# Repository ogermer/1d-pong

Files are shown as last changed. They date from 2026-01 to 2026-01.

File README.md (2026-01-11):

# 1D Pong

A two-player reaction game played on a single strip of WS2812B LEDs. Players compete by pressing their button at the right moment when the ball enters their zone.

## Features

- Fast-paced two-player gameplay
- Dynamic difficulty: zones shrink after each point
- Early-hit bonus: hit the ball as it enters your zone for extra speed
- 13 attract mode animations to draw players in
- Modular animation system for easy customization
- Visual feedback for hits, misses, and scoring
- Configurable game parameters

## Hardware Requirements

### Components

| Component | Specification | Quantity |
|---|---|---|
| Microcontroller | WEMOS D1 Mini ESP32 | 1 |
| LED Strip | WS2812B, 55 LEDs | 1 |
| Buttons | Momentary push button | 2 |
| Power Supply | 5V, 3A recommended | 1 |
| Wires | Jumper wires | As needed |

### Schematic

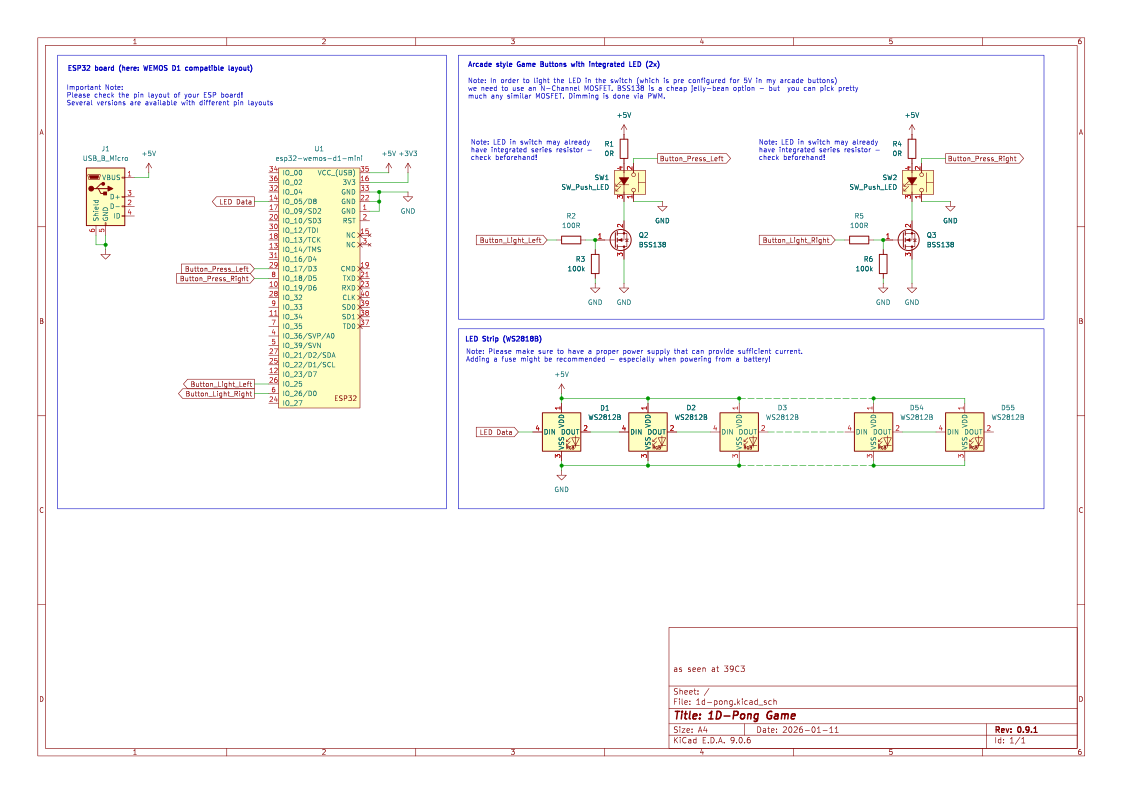
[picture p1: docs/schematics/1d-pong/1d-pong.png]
Schematic Diagram


[Download PDF Schematic](docs/schematics/1d-pong/1d-pong.pdf)

### Pin Connections

| Component | ESP32 Pin |
|---|---|
| LED Data | GPIO 5 |
| Left Button | GPIO 17 |
| Right Button | GPIO 18 |
| Left Button LED | GPIO 25 (PWM) |
| Right Button LED | GPIO 26 (PWM) |
| LED Power | 5V |
| LED Ground | GND |
| Buttons | GND (active LOW with internal pull-up) |

### Photos

<!-- Add your project photos to docs/images/ -->
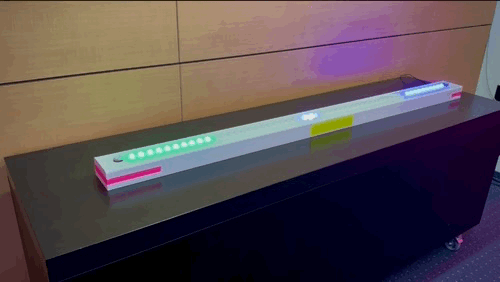
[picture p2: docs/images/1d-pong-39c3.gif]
Project Photo

<!-- ![Project Detail](docs/images/project-photo-2.jpg) -->

## Installation

### Prerequisites

- [VS Code](https://code.visualstudio.com/)
- [PlatformIO Extension](https://platformio.org/install/ide?install=vscode)

### Setup

1. Clone the repository:
   ```bash
   git clone https://github.com/yourusername/1d-pong.git
   cd 1d-pong
   ```

2. Open the project in VS Code:
   ```bash
   code .
   ```

3. Build the project:
   - Click the checkmark icon in the PlatformIO toolbar, or
   - Press `Ctrl+Alt+B`

4. Upload to your ESP32:
   - Connect your ESP32 via USB
   - Click the arrow icon in the PlatformIO toolbar, or
   - Press `Ctrl+Alt+U`

### Configuration

Edit `include/config.h` to customize:

```cpp
// Hardware
#define NUM_LEDS            55      // Number of LEDs in your strip
#define LED_PIN             5       // Data pin for LED strip
#define BUTTON_LEFT_PIN     17      // Left player button
#define BUTTON_RIGHT_PIN    18      // Right player button

// Button LEDs (PWM capable pins)
#define BUTTON_LED_LEFT_PIN  25     // Left button LED
#define BUTTON_LED_RIGHT_PIN 26     // Right button LED
#define BUTTON_LED_PWM_FREQ  5000   // 5kHz PWM frequency
#define BUTTON_LED_PWM_RES   8      // 8-bit resolution (0-255)

// Game Parameters
#define ZONE_SIZE_START     10      // Initial zone size (LEDs)
#define ZONE_SIZE_MIN       5       // Minimum zone size
#define SCORE_TO_WIN        5       // Points to win a match

// Speed
#define BALL_INITIAL_DELAY_MS  60   // Starting ball speed (lower = faster)

// Animation
#define ANIMATION_DURATION_MS  10000UL  // Duration per animation (ms)
```

## How to Play

### Starting a Game

1. When idle, the LED strip displays attract mode animations
2. Either player presses their button to start a match
3. The ball spawns in the center after a countdown

### Gameplay

1. The ball (white LED) travels toward one player's zone
2. When the ball enters your zone (colored section), press your button to return it
3. The ball speeds up with each successful return
4. Score a point when your opponent misses

### Scoring

- **Miss**: Ball exits the strip = opponent scores
- **Early press**: Pressing outside your zone = opponent scores
- **First to 5 points wins** the match

### Advanced Mechanics

- **Early-hit bonus**: Hitting the ball as it enters your zone (not waiting until it's about to exit) adds extra speed, making it harder for your opponent
- **Shrinking zones**: After each point, both zones shrink by 1 LED, increasing difficulty

## Game State Machine

```mermaid
stateDiagram-v2
    [*] --> IDLE
    IDLE --> SERVE : Button Press
    SERVE --> BALL_MOVING : Countdown Complete
    BALL_MOVING --> BALL_MOVING : Successful Hit
    BALL_MOVING --> CHECK_GAME_OVER : Miss or Penalty
    CHECK_GAME_OVER --> SERVE : Score < 5
    CHECK_GAME_OVER --> GAME_OVER : Score ≥ 5
    GAME_OVER --> IDLE : Win Animation Complete

    note right of IDLE
        Attract mode animations
        Button LED breathing & pulses
    end note

    note right of SERVE
        Countdown with visual pulse
        Zone shrinks after each point
    end note

    note right of BALL_MOVING
        Active gameplay
        Button LEDs indicate active zones
        Flash on hit, blink on miss
    end note

    note right of GAME_OVER
        Display winner animation
        First to 5 points wins
    end note
```

### States

| State | Description |
|---|---|
| `IDLE` | Attract mode - cycling through animations, waiting for player |
| `SERVE` | Countdown before ball launch, zones displayed |
| `BALL_MOVING` | Active gameplay - ball moving, checking for hits |
| `CHECK_GAME_OVER` | Evaluate if a player has won |
| `GAME_OVER` | Display winner animation, then return to idle |

## Adding Custom Animations

The animation system uses auto-registration - simply create a new `.cpp` file in `src/animations/` and it will be automatically included.

### Step-by-Step

1. Copy the template:
   ```bash
   cp src/animations/_template.cpp.example src/animations/my_animation.cpp
   ```

2. Edit your new file:
   ```cpp
   #include "animation.h"

   class MyAnimation : public Animation {
   public:
       MyAnimation(const char* name) : Animation(name) {}

       void reset() override {
           // Initialize state when animation starts
           _lastUpdate = 0;
       }

       void update(CRGB* leds, uint8_t numLeds) override {
           // Non-blocking timing
           if (millis() - _lastUpdate < 50) return;
           _lastUpdate = millis();

           // Your animation logic here
           fill_solid(leds, numLeds, CRGB::Black);
           // ...

           FastLED.show();
       }

   private:
       uint32_t _lastUpdate = 0;
   };

   // Register with a display name
   REGISTER_ANIMATION(MyAnimation, "My Animation");
   ```

3. Build and upload - your animation is now in the rotation!

### Animation Guidelines

- **Non-blocking**: Never use `delay()` - use `millis()` for timing
- **Call `FastLED.show()`**: Required to display your changes
- **Use `reset()`**: Initialize state variables when animation starts
- **Available helpers**: `fill_solid()`, `CHSV()`, `sin8()`, `qadd8()`, `qsub8()`, etc.

### Included Animations

| Animation | Description |
|---|---|
| Rainbow Dot | Rainbow background with bouncing white dot |
| Pong Demo | Simulated game demonstration |
| Plasma Comet | Plasma background with white comet trail |
| Cylon | Scanning red eye effect |
| Fire | Flames from both player zones |
| Sparkle | Twinkling stars with shooting stars |
| Duel Chase | Blue/green dots colliding |
| Heartbeat | Pulsing red heartbeat |
| Ocean Wave | Blue sine waves with foam |
| Bouncing Balls | Physics-based bouncing balls |
| Matrix Rain | Green digital rain |
| Lightning Storm | Random flashes with thunder |
| Color Breathing | Slow color pulsing |

## Troubleshooting

### LEDs not lighting up

- Check power supply voltage (5V) and amperage (3A recommended for 55 LEDs)
- Verify data pin connection (GPIO 5 by default)
- Ensure correct LED type in config (`WS2812B`)
- Check color order setting (`GRB` for most WS2812B strips)

### Buttons not responding

- Verify button connections to correct GPIO pins
- Buttons should connect between GPIO and GND (uses internal pull-up)
- Check for loose connections

### Upload fails

- Try holding BOOT button on ESP32 while uploading
- Check USB cable (some are power-only)
- Verify correct board selected in `platformio.ini`

### Game too fast/slow

- Adjust `BALL_INITIAL_DELAY_MS` in `config.h`
- Higher values = slower ball
- Recommended range: 40-80ms

## Project Structure

```
1d-pong/
├── platformio.ini          # PlatformIO configuration
├── include/
│   ├── config.h            # Game and hardware configuration
│   └── animation.h         # Animation base class
├── src/
│   ├── main.cpp            # Game logic and state machine
│   ├── animation.cpp       # Animation manager
│   └── animations/         # Animation implementations
│       ├── _template.cpp.example
│       ├── rainbow_dot.cpp
│       ├── fire.cpp
│       └── ...
└── README.md
```

## Development Note

This project was developed with assistance from AI tools (Claude, ChatGPT, etc.). All code has been reviewed and tested by the author.

## Contributing

Contributions are welcome! Here's how you can help:

1. **Fork** the repository
2. **Create** a feature branch (`git checkout -b feature/amazing-animation`)
3. **Commit** your changes (`git commit -m 'Add amazing animation'`)
4. **Push** to the branch (`git push origin feature/amazing-animation`)
5. **Open** a Pull Request

### Ideas for Contributions

- New attract mode animations
- Sound effects support (buzzer/speaker)
- Web-based configuration interface
- Score persistence (EEPROM)
- Tournament mode (best of N matches)
- Single-player mode with AI

## Future Improvements

- [ ] Add sound effects for hits and misses
- [ ] Web interface for configuration
- [ ] Bluetooth controller support
- [ ] High score tracking
- [ ] Adjustable difficulty modes
- [ ] More visual feedback options
- [x] Button LED integration for gameplay feedback and attract animations
  - Note: Button LEDs have integrated resistors for 5V operation and require level shifters or transistors/MOSFETs to drive from ESP32

## Credits

This project was inspired by a 1D Pong game seen at [38C3](https://events.ccc.de/) (38th Chaos Communication Congress).

Built with:
- [FastLED](https://github.com/FastLED/FastLED) - LED control library
- [PlatformIO](https://platformio.org/) - Development platform
- [Arduino-ESP32](https://github.com/espressif/arduino-esp32) - ESP32 Arduino core

## License

This project is licensed under the MIT License - see below for details.

```
MIT License

Copyright (c) 2025

Permission is hereby granted, free of charge, to any person obtaining a copy
of this software and associated documentation files (the "Software"), to deal
in the Software without restriction, including without limitation the rights
to use, copy, modify, merge, publish, distribute, sublicense, and/or sell
copies of the Software, and to permit persons to whom the Software is
furnished to do so, subject to the following conditions:

The above copyright notice and this permission notice shall be included in all
copies or substantial portions of the Software.

THE SOFTWARE IS PROVIDED "AS IS", WITHOUT WARRANTY OF ANY KIND, EXPRESS OR
IMPLIED, INCLUDING BUT NOT LIMITED TO THE WARRANTIES OF MERCHANTABILITY,
FITNESS FOR A PARTICULAR PURPOSE AND NONINFRINGEMENT. IN NO EVENT SHALL THE
AUTHORS OR COPYRIGHT HOLDERS BE LIABLE FOR ANY CLAIM, DAMAGES OR OTHER
LIABILITY, WHETHER IN AN ACTION OF CONTRACT, TORT OR OTHERWISE, ARISING FROM,
OUT OF OR IN CONNECTION WITH THE SOFTWARE OR THE USE OR OTHER DEALINGS IN THE
SOFTWARE.
```

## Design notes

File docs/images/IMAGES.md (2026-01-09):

# Image Assets

Place the following images in this directory:

## Required Images

| Filename | Description | Recommended Size |
|---|---|---|
| `wiring-diagram.png` | Wiring diagram showing ESP32, LED strip, and button connections | 800x600px |
| `project-photo-1.jpg` | Photo of the finished project (front view) | 1200x800px |
| `project-photo-2.jpg` | Photo of the finished project (detail/alternate view) | 1200x800px |

## Optional Images

| Filename | Description |
|---|---|
| `gameplay.gif` | Animated GIF showing gameplay |
| `attract-mode.gif` | Animated GIF showing attract animations |
| `components.jpg` | Photo of all components before assembly |

## Image Guidelines

- Use PNG for diagrams and screenshots
- Use JPG for photos
- Use GIF for animations (keep file size reasonable, <5MB)
- Optimize images for web viewing

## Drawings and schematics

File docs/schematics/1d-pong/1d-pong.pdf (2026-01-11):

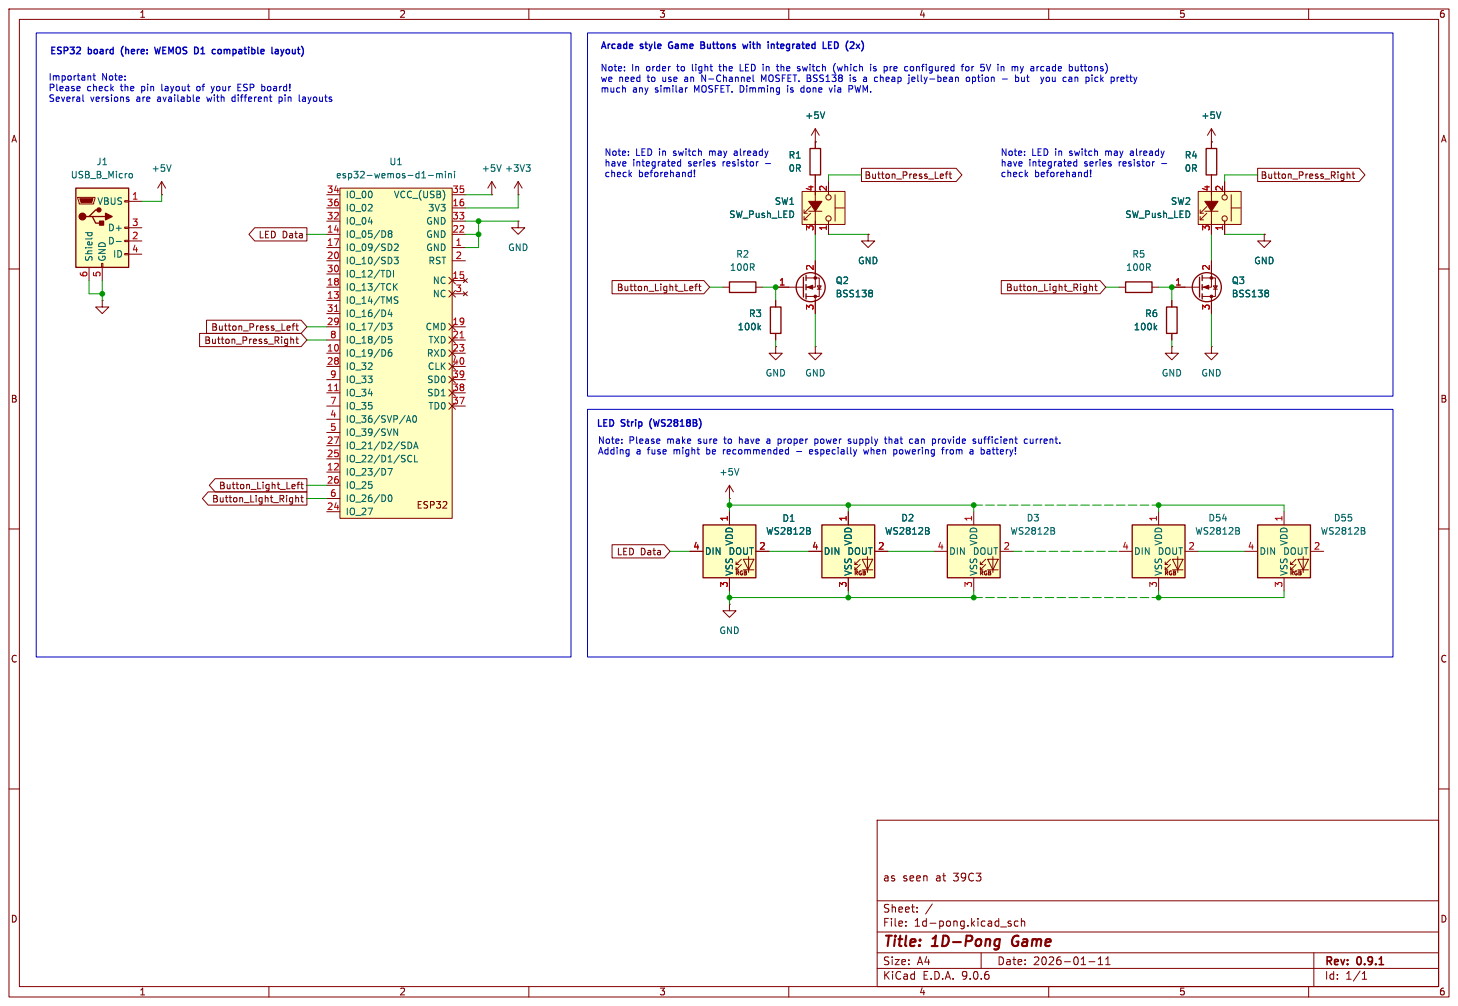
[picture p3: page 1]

File: 1d-pong.kicad_sch Sheet: / as seen at 39C3

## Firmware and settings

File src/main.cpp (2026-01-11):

#include <Arduino.h>
#include <FastLED.h>
#include "config.h"
#include "animation.h"
#include "button_led.h"

// ======================================================
// LED Array
// ======================================================
CRGB leds[NUM_LEDS];

// ======================================================
// Game State
// ======================================================
enum PlayerSide : uint8_t { PLAYER_LEFT = 0, PLAYER_RIGHT = 1 };

struct ButtonEvent {
    PlayerSide player;
    uint32_t   timestampMs;
};

QueueHandle_t buttonQueue;

enum GameState {
    STATE_IDLE,
    STATE_SERVE,
    STATE_BALL_MOVING,
    STATE_CHECK_GAME_OVER,
    STATE_GAME_OVER
};

volatile GameState currentState = STATE_IDLE;

int      ballPos        = NUM_LEDS / 2;
int      ballDir        = 1;
uint16_t ballDelayMs    = BALL_DELAY_START;
uint8_t  scoreLeft      = 0;
uint8_t  scoreRight     = 0;
uint8_t  currentZoneSize = ZONE_SIZE_START;
PlayerSide lastLoser    = PLAYER_LEFT;

// ======================================================
// Rendering Helpers
// ======================================================
void clearLeds() {
    fill_solid(leds, NUM_LEDS, COLOR_BACKGROUND);
}

void drawZones() {
    for (uint8_t i = 0; i < currentZoneSize; i++) {
        leds[i] = COLOR_ZONE_LEFT;
        leds[NUM_LEDS - 1 - i] = COLOR_ZONE_RIGHT;
    }
}

void drawBall() {
    if (ballPos >= 0 && ballPos < NUM_LEDS) {
        leds[ballPos] = COLOR_BALL;

        // 3-LED comet trail
        int t1 = ballPos - ballDir;
        int t2 = ballPos - 2 * ballDir;
        int t3 = ballPos - 3 * ballDir;

        if (t1 >= 0 && t1 < NUM_LEDS) {
            leds[t1] = CRGB::White;
            leds[t1].fadeToBlackBy(160);
        }
        if (t2 >= 0 && t2 < NUM_LEDS) {
            leds[t2] = CRGB::White;
            leds[t2].fadeToBlackBy(210);
        }
        if (t3 >= 0 && t3 < NUM_LEDS) {
            leds[t3] = CRGB::White;
            leds[t3].fadeToBlackBy(240);
        }
    }
}

void showKeypressFeedback(PlayerSide player) {
    CRGB savedLeft[ZONE_SIZE_START];
    CRGB savedRight[ZONE_SIZE_START];

    for (uint8_t i = 0; i < currentZoneSize; i++) {
        savedLeft[i]  = leds[i];
        savedRight[i] = leds[NUM_LEDS - 1 - i];
    }

    CRGB orange = CRGB(255, 80, 0);
    if (player == PLAYER_LEFT) {
        for (uint8_t i = 0; i < currentZoneSize; i++) leds[i] = orange;
    } else {
        for (uint8_t i = 0; i < currentZoneSize; i++) leds[NUM_LEDS - 1 - i] = orange;
    }

    FastLED.show();
    vTaskDelay(pdMS_TO_TICKS(80));

    if (player == PLAYER_LEFT) {
        for (uint8_t i = 0; i < currentZoneSize; i++) leds[i] = savedLeft[i];
    } else {
        for (uint8_t i = 0; i < currentZoneSize; i++) leds[NUM_LEDS - 1 - i] = savedRight[i];
    }

    FastLED.show();
}

void drawScoreOverlay() {
    const uint8_t c = NUM_LEDS / 2;
    for (uint8_t i = 0; i < scoreLeft && (c - 1 - i) >= 0; i++) {
        leds[c - 1 - i] += CRGB(0, 0, 100);
    }
    for (uint8_t i = 0; i < scoreRight && (c + 1 + i) < NUM_LEDS; i++) {
        leds[c + 1 + i] += CRGB(0, 100, 0);
    }
}

void showMissAnimation(PlayerSide p) {
    for (uint8_t f = 0; f < 3; f++) {
        clearLeds();
        if (p == PLAYER_LEFT) {
            for (uint8_t i = 0; i < currentZoneSize; i++) leds[i] = COLOR_MISS;
        } else {
            for (uint8_t i = 0; i < currentZoneSize; i++) leds[NUM_LEDS - 1 - i] = COLOR_MISS;
        }
        FastLED.show();
        vTaskDelay(pdMS_TO_TICKS(120));
        clearLeds();
        FastLED.show();
        vTaskDelay(pdMS_TO_TICKS(80));
    }
}

void showWinAnimation(PlayerSide w) {
    CRGB col = (w == PLAYER_LEFT) ? COLOR_WIN_LEFT : COLOR_WIN_RIGHT;
    for (uint8_t r = 0; r < 10; r++) {
        fill_solid(leds, NUM_LEDS, col);
        FastLED.show();
        vTaskDelay(pdMS_TO_TICKS(120));
        clearLeds();
        FastLED.show();
        vTaskDelay(pdMS_TO_TICKS(80));
    }
    currentZoneSize = ZONE_SIZE_START;
}

void resetMatch() {
    scoreLeft = scoreRight = 0;
    ballDelayMs = BALL_DELAY_START;
    lastLoser = PLAYER_LEFT;
    currentZoneSize = ZONE_SIZE_START;
}

int randomDirection() {
    return (random(0, 2) == 0) ? -1 : 1;
}

void prepareServe() {
    ballPos = NUM_LEDS / 2;
    ballDelayMs = BALL_DELAY_START;

    if (scoreLeft == 0 && scoreRight == 0) {
        ballDir = randomDirection();
    } else {
        ballDir = (lastLoser == PLAYER_LEFT) ? -1 : +1;
    }

    if (scoreLeft + scoreRight > 0 && currentZoneSize > ZONE_SIZE_MIN) {
        currentZoneSize--;
    }

    for (int c = 3; c > 0; --c) {
        clearLeds();
        drawZones();
        leds[NUM_LEDS / 2] = CRGB::Yellow;
        FastLED.show();
        ButtonLED::pulseCountdown(255);  // Bright pulse
        vTaskDelay(pdMS_TO_TICKS(200));
        clearLeds();
        drawZones();
        FastLED.show();
        ButtonLED::pulseCountdown(0);  // Off
        vTaskDelay(pdMS_TO_TICKS(200));
    }
    ButtonLED::setOff();  // Ensure off after countdown
}

// ======================================================
// Tasks
// ======================================================
void buttonTask(void* pvParameters) {
    (void)pvParameters;
    pinMode(BUTTON_LEFT_PIN, INPUT_PULLUP);
    pinMode(BUTTON_RIGHT_PIN, INPUT_PULLUP);

    bool lastL = digitalRead(BUTTON_LEFT_PIN) == BUTTON_ACTIVE_LEVEL;
    bool lastR = digitalRead(BUTTON_RIGHT_PIN) == BUTTON_ACTIVE_LEVEL;
    bool stableL = lastL, stableR = lastR;
    uint32_t changeL = millis(), changeR = millis();
    const uint32_t debounceMs = 20;

    for (;;) {
        uint32_t now = millis();
        bool rawL = digitalRead(BUTTON_LEFT_PIN) == BUTTON_ACTIVE_LEVEL;
        bool rawR = digitalRead(BUTTON_RIGHT_PIN) == BUTTON_ACTIVE_LEVEL;

        if (rawL != lastL) {
            lastL = rawL;
            changeL = now;
        } else if ((now - changeL) >= debounceMs && stableL != rawL) {
            stableL = rawL;
            if (stableL) {
                ButtonEvent ev{PLAYER_LEFT, now};
                xQueueSend(buttonQueue, &ev, 0);
            }
        }

        if (rawR != lastR) {
            lastR = rawR;
            changeR = now;
        } else if ((now - changeR) >= debounceMs && stableR != rawR) {
            stableR = rawR;
            if (stableR) {
                ButtonEvent ev{PLAYER_RIGHT, now};
                xQueueSend(buttonQueue, &ev, 0);
            }
        }

        vTaskDelay(pdMS_TO_TICKS(5));
    }
}

void gameTask(void* pvParameters) {
    (void)pvParameters;
    currentState = STATE_IDLE;

    AnimationManager& animManager = AnimationManager::getInstance();
    animManager.resetToFirst();

    Serial.printf("Loaded %d animations\n", animManager.getCount());

    for (;;) {
        switch (currentState) {

        case STATE_IDLE: {
            ButtonEvent ev;
            if (xQueueReceive(buttonQueue, &ev, 0) == pdTRUE) {
                resetMatch();
                clearLeds();
                FastLED.show();
                currentState = STATE_SERVE;
                break;
            }
            // Run attract mode animations
            animManager.update(leds, NUM_LEDS);

            // Button LED idle effects
            ButtonLED::updateBreathing();
            ButtonLED::triggerAttentionPulse();
            break;
        }

        case STATE_SERVE:
            prepareServe();
            currentState = STATE_BALL_MOVING;
            break;

        case STATE_BALL_MOVING: {
            bool leftPressed = false, rightPressed = false;
            ButtonEvent ev;
            while (xQueueReceive(buttonQueue, &ev, 0) == pdTRUE) {
                if (ev.player == PLAYER_LEFT) leftPressed = true;
                if (ev.player == PLAYER_RIGHT) rightPressed = true;
            }

            ballPos += ballDir;

            bool inLeft  = (ballPos >= 0 && ballPos < (int)currentZoneSize);
            bool inRight = (ballPos >= (int)NUM_LEDS - (int)currentZoneSize);

            // Button LED active zone indication
            ButtonLED::setActiveZone(inLeft, inRight);

            // Penalty: press outside zone
            if (leftPressed && !inLeft) {
                ButtonLED::blinkMiss(true);  // Left button LED blinks
                showMissAnimation(PLAYER_LEFT);
                scoreRight++;
                lastLoser = PLAYER_LEFT;
                currentState = STATE_CHECK_GAME_OVER;
                break;
            }
            if (rightPressed && !inRight) {
                ButtonLED::blinkMiss(false);  // Right button LED blinks
                showMissAnimation(PLAYER_RIGHT);
                scoreLeft++;
                lastLoser = PLAYER_RIGHT;
                currentState = STATE_CHECK_GAME_OVER;
                break;
            }

            // Successful hit with early-hit bonus
            // Early hit = ball just entered zone, late hit = ball about to exit
            if (inLeft && leftPressed) {
                ButtonLED::flashHit(true);  // Left button LED flash
                showKeypressFeedback(PLAYER_LEFT);
                ballDir = +1;

                // Calculate early hit factor: 1.0 at zone entry, 0.0 at zone exit
                // Left zone: entry at currentZoneSize-1, exit at 0
                float earlyFactor = (currentZoneSize > 1)
                    ? (float)ballPos / (float)(currentZoneSize - 1)
                    : 0.0f;
                uint16_t totalSpeedup = BALL_SPEEDUP_PER_RETURN +
                    (uint16_t)(earlyFactor * BALL_EARLY_HIT_MAX_BONUS);

                if (ballDelayMs > BALL_DELAY_MIN + totalSpeedup)
                    ballDelayMs -= totalSpeedup;
                else
                    ballDelayMs = BALL_DELAY_MIN;
            }
            if (inRight && rightPressed) {
                ButtonLED::flashHit(false);  // Right button LED flash
                showKeypressFeedback(PLAYER_RIGHT);
                ballDir = -1;

                // Calculate early hit factor: 1.0 at zone entry, 0.0 at zone exit
                // Right zone: entry at NUM_LEDS-currentZoneSize, exit at NUM_LEDS-1
                float earlyFactor = (currentZoneSize > 1)
                    ? (float)(NUM_LEDS - 1 - ballPos) / (float)(currentZoneSize - 1)
                    : 0.0f;
                uint16_t totalSpeedup = BALL_SPEEDUP_PER_RETURN +
                    (uint16_t)(earlyFactor * BALL_EARLY_HIT_MAX_BONUS);

                if (ballDelayMs > BALL_DELAY_MIN + totalSpeedup)
                    ballDelayMs -= totalSpeedup;
                else
                    ballDelayMs = BALL_DELAY_MIN;
            }

            // Normal miss
            if (ballPos < 0) {
                ButtonLED::blinkMiss(true);  // Left button LED blinks
                showMissAnimation(PLAYER_LEFT);
                scoreRight++;
                lastLoser = PLAYER_LEFT;
                currentState = STATE_CHECK_GAME_OVER;
                break;
            }
            if (ballPos >= NUM_LEDS) {
                ButtonLED::blinkMiss(false);  // Right button LED blinks
                showMissAnimation(PLAYER_RIGHT);
                scoreLeft++;
                lastLoser = PLAYER_RIGHT;
                currentState = STATE_CHECK_GAME_OVER;
                break;
            }

            // Render frame
            clearLeds();
            drawZones();
            drawBall();
            drawScoreOverlay();
            FastLED.show();

            vTaskDelay(pdMS_TO_TICKS(ballDelayMs));
            break;
        }

        case STATE_CHECK_GAME_OVER:
            currentState = (scoreLeft >= SCORE_TO_WIN || scoreRight >= SCORE_TO_WIN)
                           ? STATE_GAME_OVER : STATE_SERVE;
            break;

        case STATE_GAME_OVER: {
            PlayerSide winner = (scoreLeft >= SCORE_TO_WIN) ? PLAYER_LEFT : PLAYER_RIGHT;
            showWinAnimation(winner);
            // Reset to first animation after game ends
            animManager.resetToFirst();
            currentState = STATE_IDLE;
            break;
        }
        }
    }
}

// ======================================================
// Setup & Loop
// ======================================================
void setup() {
    Serial.begin(115200);
    delay(200);

    FastLED.addLeds<LED_TYPE, LED_PIN, COLOR_ORDER>(leds, NUM_LEDS);
    FastLED.setBrightness(BRIGHTNESS);
    clearLeds();
    FastLED.show();

    // Initialize button LEDs
    ButtonLED::init();

    buttonQueue = xQueueCreate(10, sizeof(ButtonEvent));

    xTaskCreatePinnedToCore(buttonTask, "Btn",  4096, NULL, 2, NULL, 0);
    xTaskCreatePinnedToCore(gameTask,   "Game", 8192, NULL, 1, NULL, 1);

    Serial.println("1D-Pong - Modular Animation System");
}

void loop() {
    vTaskDelay(pdMS_TO_TICKS(1000));
}

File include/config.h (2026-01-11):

#pragma once

// ======================================================
// Hardware Configuration
// ======================================================
#define LED_PIN             5
#define NUM_LEDS            55
#define LED_TYPE            WS2812B
#define COLOR_ORDER         GRB
#define BUTTON_LEFT_PIN     17
#define BUTTON_RIGHT_PIN    18
#define BUTTON_ACTIVE_LEVEL LOW

// Button LEDs (PWM capable pins)
#define BUTTON_LED_LEFT_PIN  25
#define BUTTON_LED_RIGHT_PIN 26
#define BUTTON_LED_PWM_FREQ  5000  // 5kHz PWM frequency
#define BUTTON_LED_PWM_RES   8     // 8-bit resolution (0-255)

// ======================================================
// Global Brightness
// ======================================================
#define BRIGHTNESS          255

// ======================================================
// Animation Configuration
// ======================================================
#define ANIMATION_DURATION_MS  10000UL    // Duration each animation plays before switching

// ======================================================
// Game Parameters
// ======================================================
#define ZONE_SIZE_START     10
#define ZONE_SIZE_MIN       5
#define SCORE_TO_WIN        5

// ======================================================
// Ball Speed Control
// ======================================================
#define BALL_INITIAL_DELAY_MS  60    // Main tuning knob for ball speed

// Derived values (scale automatically from BALL_INITIAL_DELAY_MS)
#define BALL_DELAY_START        BALL_INITIAL_DELAY_MS
#define BALL_DELAY_MIN          (BALL_INITIAL_DELAY_MS / 5)
#define BALL_SPEEDUP_PER_RETURN (BALL_INITIAL_DELAY_MS / 14)

// Early hit bonus: hitting the ball as it enters the zone gives extra speedup
// Max bonus when ball just entered zone, 0 bonus when ball is about to exit
#define BALL_EARLY_HIT_MAX_BONUS (BALL_INITIAL_DELAY_MS / 8)  // ~7ms bonus at 60ms base

// ======================================================
// Colors
// ======================================================
#define COLOR_BACKGROUND    CRGB::Black
#define COLOR_BALL          CRGB::White
#define COLOR_ZONE_LEFT     CRGB::Blue
#define COLOR_ZONE_RIGHT    CRGB::Green
#define COLOR_MISS          CRGB::Red
#define COLOR_WIN_LEFT      CRGB::Blue
#define COLOR_WIN_RIGHT     CRGB::Green

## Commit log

2026-01-09 Add button LED integration to future improvements
2026-01-11 Add button LED integration and Mermaid state diagram
    Button LED Features:
    - GPIO 25 (left) and GPIO 26 (right) PWM control
    - Gameplay feedback: active zone indication, hit flash, miss blinks
    - Countdown synchronization with visual pulse
    - Idle mode: breathing pattern and attention pulses
    - MOSFET-compatible for flexible voltage supply
    Documentation:
    - Replaced ASCII state diagram with Mermaid for better visualization
    - Added button LED effects to state machine notes
    [button_led.cpp, config.h, main.cpp]
2026-01-11 Add button LED GPIO pins to pin connections table
    Added GPIO 25 and GPIO 26 entries for button LEDs in hardware documentation.
2026-01-11 Add KiCad schematic to documentation
    - Added schematic diagram section with embedded SVG
    - Included PDF download link for printable version
    - Added KiCad project files for editing
    [1d-pong.kicad_pcb, 1d-pong.kicad_sch]
2026-01-11 Use PNG schematic for dark mode compatibility
    Converted SVG to PNG with white background for better readability in dark mode.
    SVG file retained in repository.
2026-01-11 Document button LED configuration and mark as implemented
    - Added button LED GPIO pins and PWM settings to configuration section
    - Marked button LED integration as completed in future improvements
2026-01-11 Update schematic with comments and revised part numbering
    Regenerated PNG from updated SVG with white background.
    [1d-pong.kicad_sch]
